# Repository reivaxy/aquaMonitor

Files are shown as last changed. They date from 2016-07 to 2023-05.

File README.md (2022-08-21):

# aquaMonitor

### Warning: I'm no longer working on this project, I'm replacing it with iotinator (https://github.com/reivaxy/iotinator) which is not focused on aquarium monitoring but provides a framework to monitor and/or control "anything" in your house (including aquariums), with a modular architecture, smaller and cheaper components.

The esp8266 evolution (which is working) will never be more than a prototype, while the earlier version (No wifi, only in and out SMS) is fully functional, two devices currently running 24/7 since spring 2015.)

AquaMonitor is a device to monitor a recifal aquarium (or reef tank) with an Arduino Mega board and send SMS alerts when vitals are bad.

Monitors light level, temperature, water level, main power failure, and sends SMS to all registered mobile phone numbers when configurable thresholds are reached.

Settings (thresholds for light and temperature, light schedule, ...) are all managed through sending SMS (or via a web application for the prototype with ESP8266)

WebApp showing a light level alert | Example of SMS communication
-------|-------
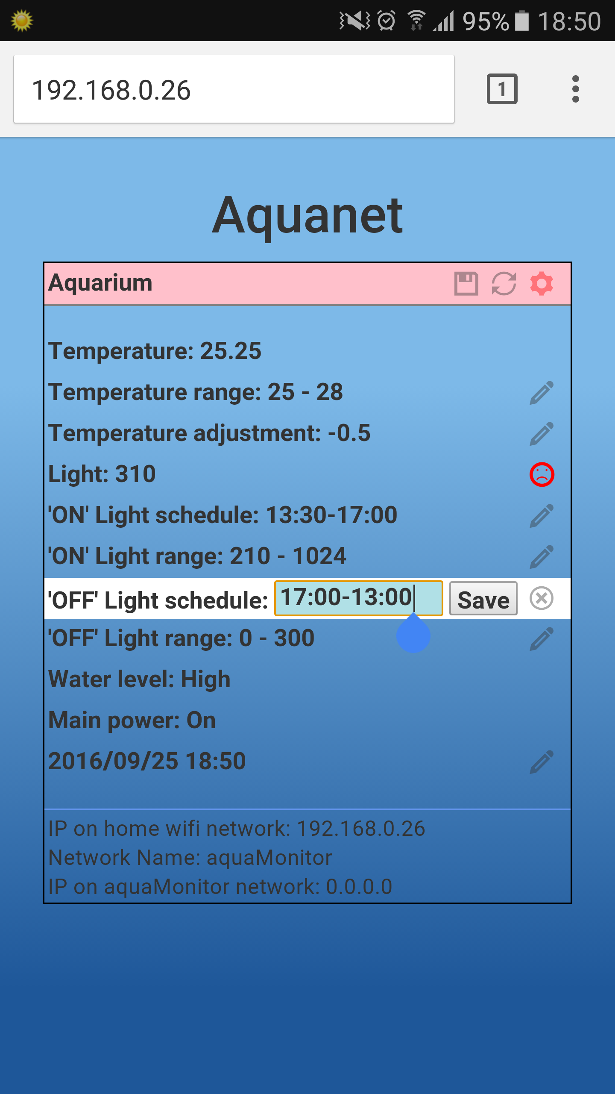
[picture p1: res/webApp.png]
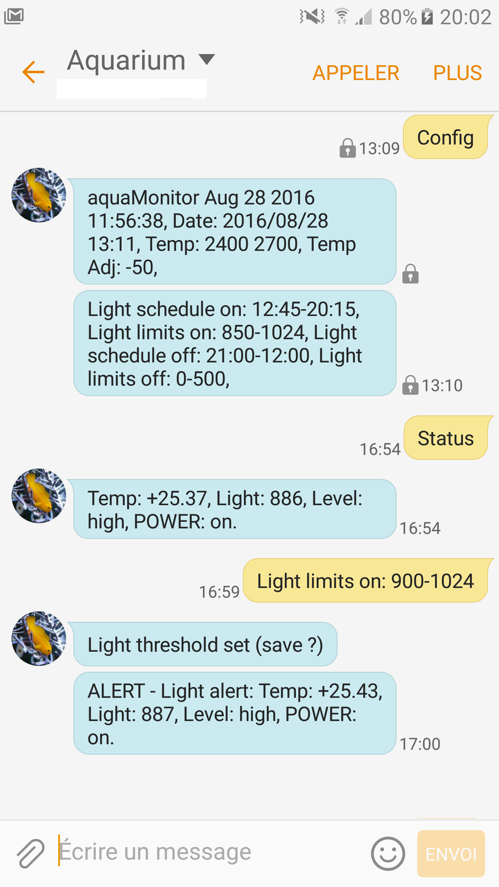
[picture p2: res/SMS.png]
 | 

Chart displaying evolution of parameters:<br/>
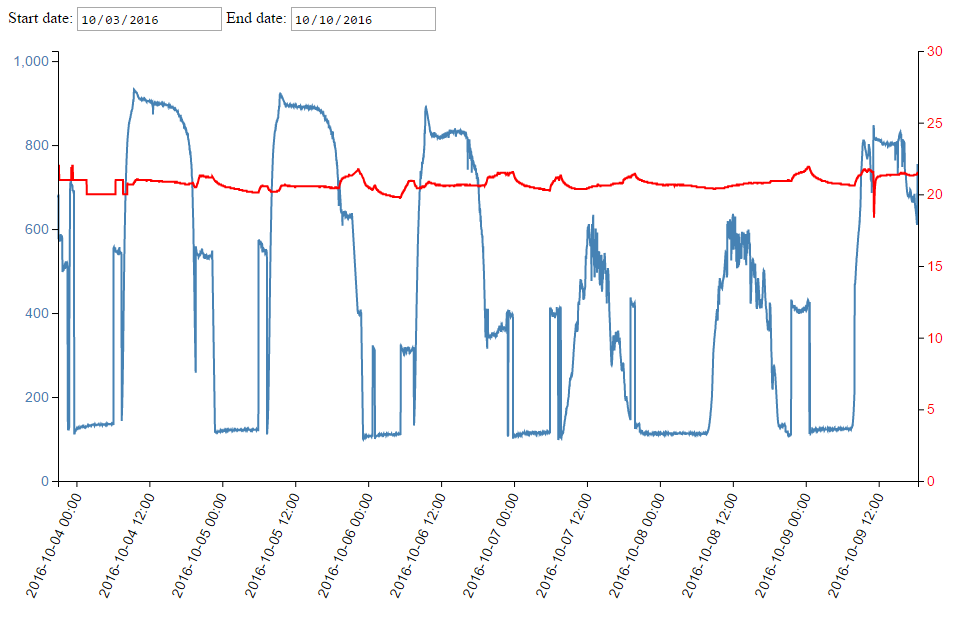
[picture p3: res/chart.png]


Device installed:<br/>
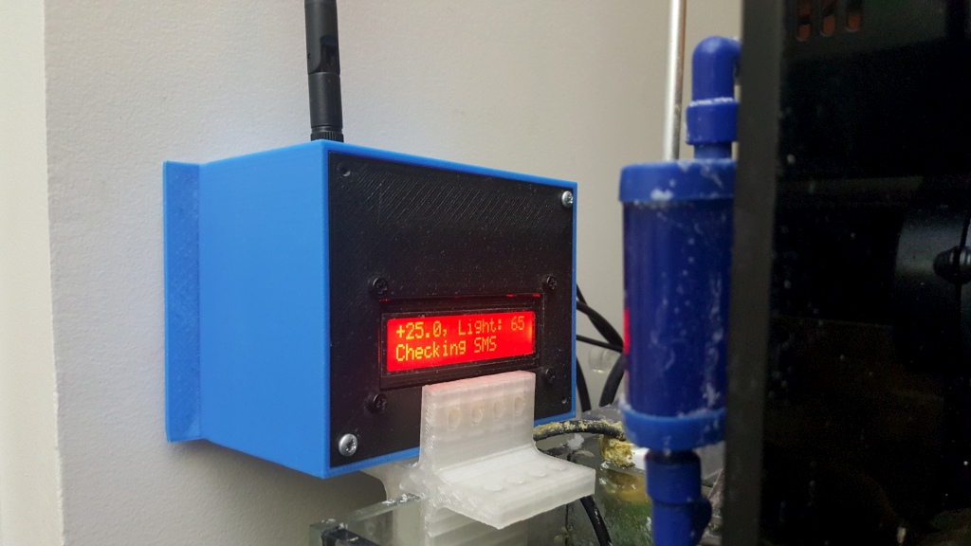
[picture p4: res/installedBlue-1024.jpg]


Although project comes with 3D files to print the <a href="https://github.com/reivaxy/aquaMonitor/blob/master/hardware/bracket/aquaMonitorDemo.stl">triple sensor bracket (light, temperature and adjustable water level sensor)<a> and <a href="https://github.com/reivaxy/aquaMonitor/blob/master/hardware/case/case.stl">case</a>, you dont *need* a 3D printer, you can instead use a case from the market and design your own fixture for the sensors.

A PCB design (for Fritzing http://fritzing.org/home/) is provided, you can either order the PCB, make it yourself, or use a prototyping board instead.

Disclaimer: This system description is provided with no warranty whatsoever. If you use it, you accept to do so at your own risks, should a bug or any event be the cause of a malfunction.
Originally supposed to run on a UNO board, this project does not take full advantage of more advanced Mega board features.

# Libraries to add:
* MAX31850 OneWire (adafruit)
* EEPROMx
* RTC (included in this repo, not sure where it comes from)
* ArduinoJson (https://github.com/bblanchon/ArduinoJson)

# Available features
* Temperature periodical measurement
* Light periodical measurement
* Water level (high/low) detection
* Main power monitoring
* LCD scrolling display of these measures
* Connects to home wifi network
* Expose a webApp to monitor and set the parameters
* Periodically sends measures to an external website to provide charts
* Sending SMS with light, temperature, main power and water level when thresholds are reached
* Can subscribe/unsubscribe a new phone number to alerts by sending an SMS.
* Adjusting the high/low light threshold and schedules by SMS
* Adjusting the temperature value by SMS
* Adjusting the time interval when light should be on.
* Save and read params (thresholds...) to EEPROM
* Battery in case main power fails.
* Most strings stored in PROGMEM to save variable memory space, easily localizable.
* Each subscribed phone numbers can set a minimum interval between 2 alerts to avoid flooding
* Periodical checking for incoming SMS, handles messages like :
  * 'admin +33xxxxxxxx' : add this phone number with admin rights
  * 'config' : send back the config
  * 'display': Reset the display when messy (prototype contact issue ?, investigating)
  * 'interval xxx' : No more than 1 sms per xxx seconds
  * 'light XXX' : set the low light threshold for alerts
  * 'save': save the configuration (light schedule and level, temp range, subs, admin, ...) to EEPROM
  * 'schedule hh:ss - hh:ss' : set the time span during which light should be above threshold
  * 'status': send SMS back with current measures
  * 'reset sub': resets all subscriptions (admin only)
  * 'sub xxx' : subscribe to a service (alert, event)
  * 'subs' : send back list of subscribed phone numbers (admin only)
  * 'temp XXX YYY': set the low (XXX) and high (YYY) thresholds for temperature
  * 'temp adj XXX': set the temperature adjustment signed value
  * 'time 2016/07/30 11:00' : set the date and time
  * 'unsub xxx' : unsubscribe to a service (alert, event)

# TODOs
* Water movement detection to warn about pumps failure (sensor remains to be found or designed...) 
* Some more configuration by SMS (level detection switch state inversion for instance, or display shift frequency ?)
* Periodical status sending (upon registration) ?
* see roadmap for bigger planned changes (Local Access Point for slave devices to connect to)

# More pictures 

Prototype (at the time it could run on a UNO board):<br/>
<br/>

<br/><br/>
Finished:<br/>
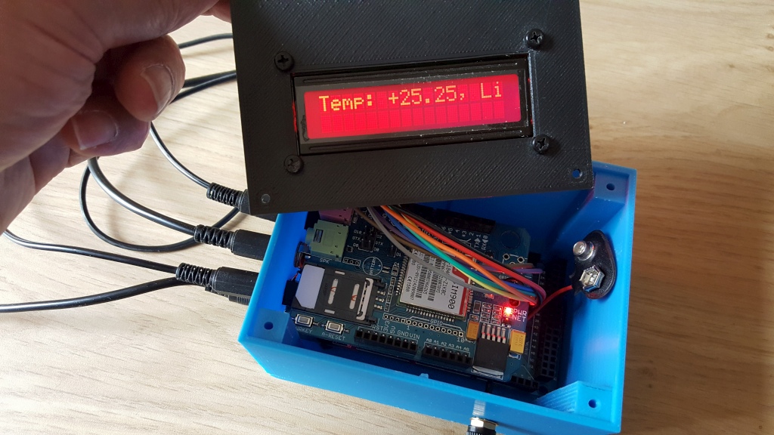
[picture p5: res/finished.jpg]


Other device installed:<br/>
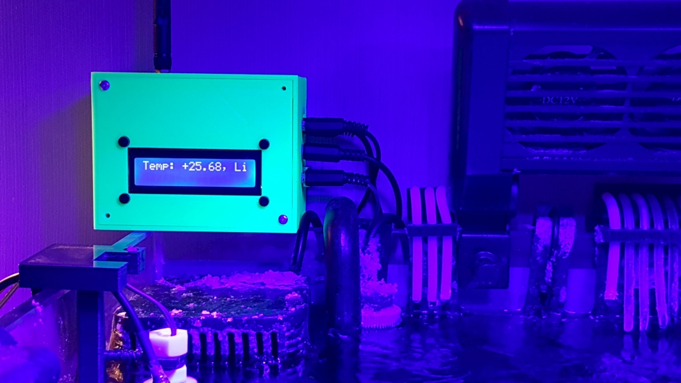
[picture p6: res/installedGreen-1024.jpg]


<br/><br/>
Sensors:<br/>


<br/><br/>

#License

<br />This work is licensed under a <a rel="license" href="http://creativecommons.org/licenses/by-nc/4.0/">Creative Commons Attribution-NonCommercial 4.0 International License</a>.

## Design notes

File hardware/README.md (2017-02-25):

# Hardware

This is the hardware stuff you'll need to build it all.

<b>Beware: schematics and PCB not yet updated with the Wifi module ESP8266. Coming soon.</b>

Here is the schematic:

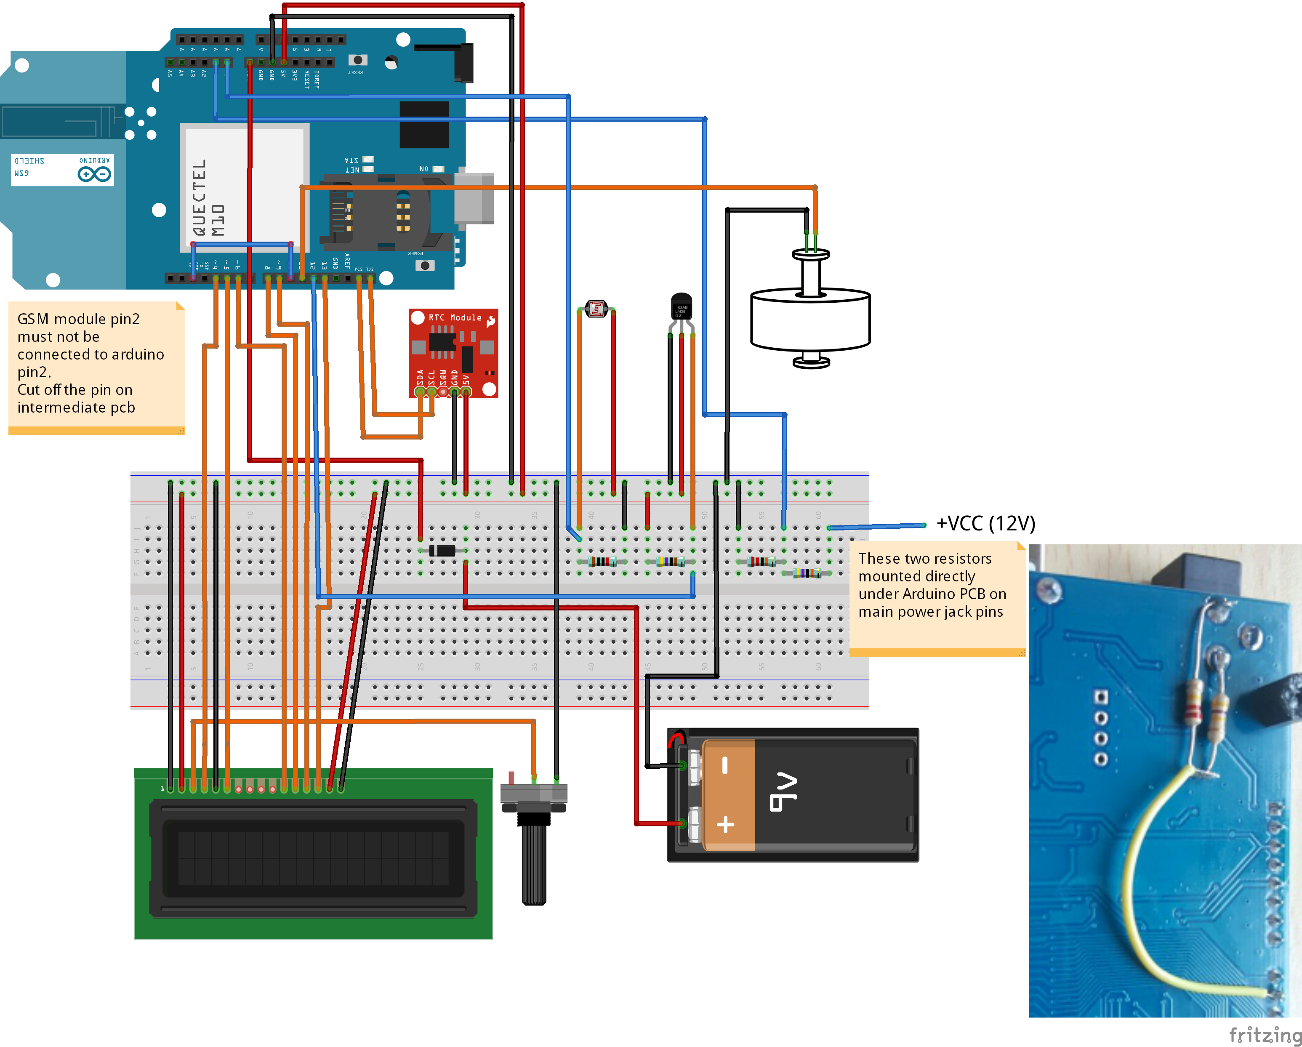
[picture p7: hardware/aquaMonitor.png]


The PCB:

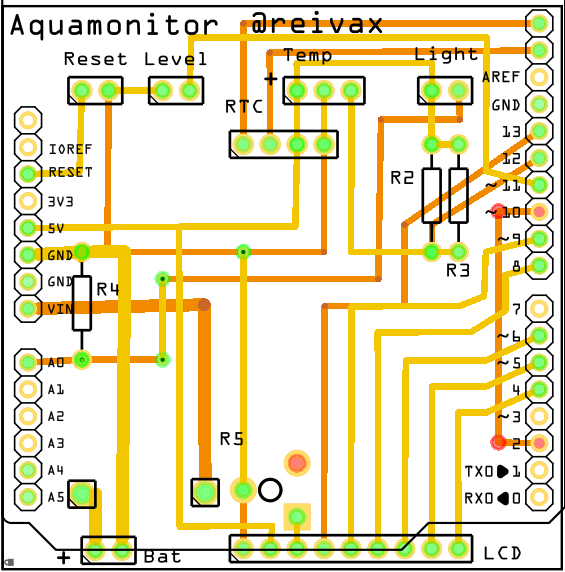
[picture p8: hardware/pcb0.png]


Here is the sensor bracket body design:



and the adjustable water level sensor bracket:



Here is the main body printed, with an unfinished prototype for the adjustable water level sensor bracket:





And, finally:







# License

<br />This work is licensed under a <a rel="license" href="http://creativecommons.org/licenses/by-nc/4.0/">Creative Commons Attribution-NonCommercial 4.0 International License</a>.

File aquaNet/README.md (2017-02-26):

# aquaNet

This is the code for the optional ESP8266 Wifi device that will allow you to:
* Access aquaMonitor through a web interface to modify the settings and run commands
* Have aquaMonitor periodically log measures to an external web site in order to build statistics
* Have several aquaMonitor modules share one GSM (hence one SIM card) to send alerts.

Use the Arduino IDE to build and upload the binary to your ESP8266 module.
The steps to set up the IDE are described here: http://randomnerdtutorials.com/how-to-install-esp8266-board-arduino-ide/

The embedded web server actually serves a minimalistic page (whose content is a string in html.h) that loads scripts **from an external web site you own**, that builds the webApp.
It makes styling the page very easy and with no need to flash the wifi module again. So most of the webApp is actually in the '<a href="https://github.com/reivaxy/aquaMonitor/tree/master/aquaNet/webSite/www/aquaNet">webSite/www/aquaNet</a>' subdirectory.

It uses jQuery, Backbone and Boostrap.

Here is what the webApp currently looks like, showing data for one module, with an alert on the light level while editing a light setting.



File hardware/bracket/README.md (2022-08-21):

The aquaMonitor.scad file contains two modules, each needs to be rendered separately and printed:

The main body, and the insert.

New version: the light sensor is enclosed in the bracket, to avoid salt and corrosion (four sensors died because of it already). This means the bracket needs to be printed with transparent ABS or PET. 

You can check the <a href="https://github.com/reivaxy/aquaMonitor/blob/master/hardware/bracket/aquaMonitorDemo.stl">aquaMonitorDemo.stl file to see a 3D rendering of the bracket</a> with its insert positionned.

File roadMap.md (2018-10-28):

Warning: this project is asleep, while I'm working on iotinator which should replace it with much better modular architecture, smaller and cheaper components, and many more features. The esp8266 version is still a prototype, while the earlier version is fully functional, two devices currently running 24/7 since spring 2015.)

#V1.0 2016/09
- Full config via SMS
- config saved in EEPROM
- monitors water level, light on level and schedule, light off level and schedule, temperature, main power
- send alerts via SMS
- logs info on serial line
- LCD display 2x20 with measures and messages
- battery backup
- extra phone numbers subscription to get alerts

#Planned evolutions

Hardware stuff:
- Investigate replacing LCD screen with Oled screen ?. Ordered for prototyping, here is the look:

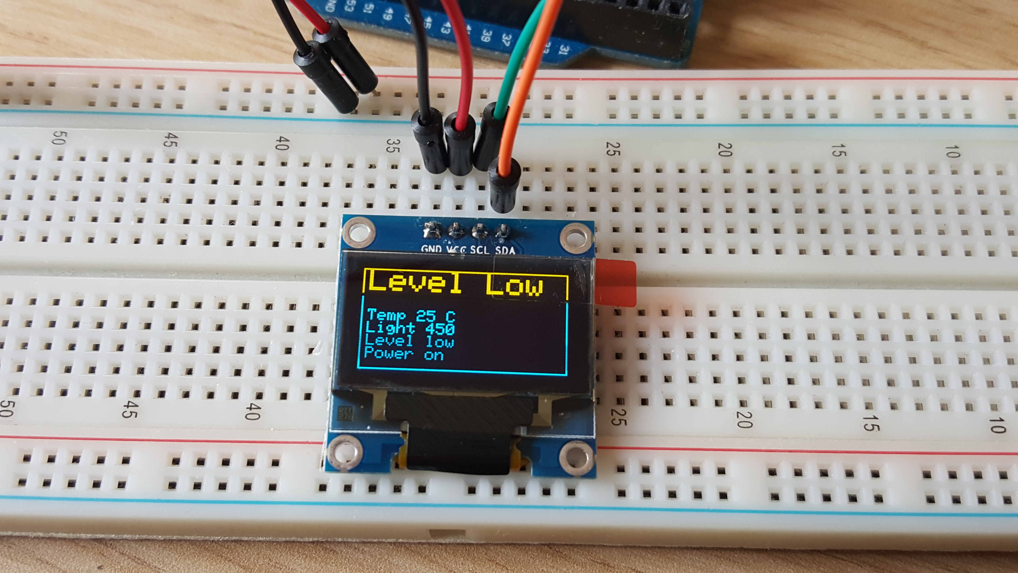
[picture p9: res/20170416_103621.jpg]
 

  Nice thing is low consumption.

- replace the 3 jack sockets with a DB15 socket ? Mechanical issue to fix on the case if wires are soldered. Need connectors :(

#V2.0 (now in master branch)
The software is mostly ready for V2 in master branch. Needs to make more settings accessible, and need schematics update (and new PCB)
- Connects to home wifi network, using ESP8266
 

- Logs all measures to external website
- expose a webApp allowing to see all data, and edit settings

The features below will be implemented in the "iotinator" project (ok sorry but it's hard to come up with a good name).
~~#V3.0
- Creates own private wifi network
- Monitors extra aquaMonitor devices connections. These ones won't have a GSM circuit, only wifi.
- Handles all connected devices to forward them configuration messages, and transmit their alerts by SMS.~~

~~#V4.0
- Any extra device will be able to create its own private wifi network to handle more devices
Would be useful for people owning more than 5 tanks. I know one.
(wifi component only accepts 4 simultaneous connections. Could multiplex, but less fun, and not as quick)~~

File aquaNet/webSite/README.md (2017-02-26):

#Statistics web server and webApp files host

This server provides an access point to record tank measures (from different tanks and users) into a database, as well as a page to display a graph from the data for a given tank:



The content of the www directory needs to be uploaded to a publicly accessible web server.

This web server hostname needs to be set into DEFAULT_WEBAPP_HOST constant in aquaMonitorSecret.h file (file that needs to be accessible when compiling the arduino and the ESP8266 firmwares, obviously not included in this repository).

The credentials to connect to your mySQL DB need to be set in the includes/myconfig.inc.php file, that must not be accessible through your server url.

The reeftanklpaqua.sql file should be used to create the DB structure (run it from command line or phpMySqlAdmin)

(Beware, there is no authentication yet between the arduino wifi module and the server, so anyone knowing the endpoints can inject data)

The www/aquaNet subdirectory contains files for the aquaNet webApp, which is a web application exposed by the wifi module.

The js and css files are loaded from the minimalist loader page served by the module to build the webApp, which allows to modify the webApp without the need for flashing the ESP8266 to improve the look, or translate messages.
This also makes using images really easier, and contributes to faster page loading, since the wifi module does not have a great bandwidth (and does not process multiple requests simultaneously).

Of course this is made possible thanks to the .htaccess directive:

Header set Access-Control-Allow-Origin "*"

The test.html page can be used to test the webApp, it will then use the getData.json test data.
It anticipates on V3 features, allowing to display data from several connected modules.

All translatable labels used in the webApp are in a css file, that will make localisation easy.

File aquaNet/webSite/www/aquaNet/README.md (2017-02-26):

#aquaNet Web application

This directory hosts the main part of the webApp exposed by the ESP8266 wifi module on the wifi local network it creates.

This external hosting makes it easy to modify the webApp with no need to flash the ESP8266, is much more convenient when using images, and provides much better performances.



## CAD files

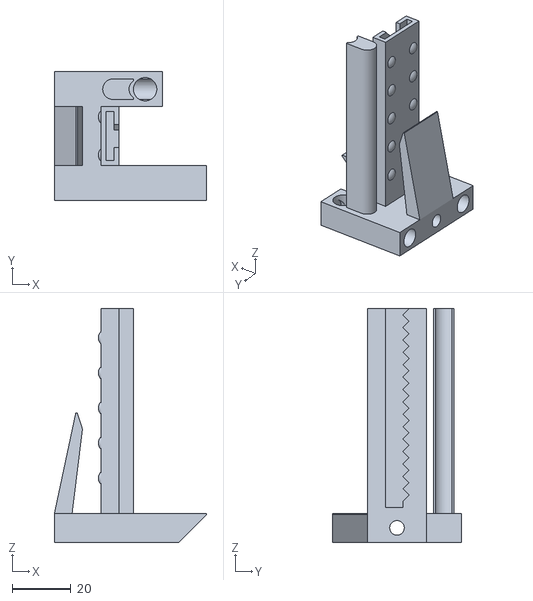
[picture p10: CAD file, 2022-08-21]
hardware/bracket/aquaMonitor6mm.stl
52.0 x 44.0 x 80.0

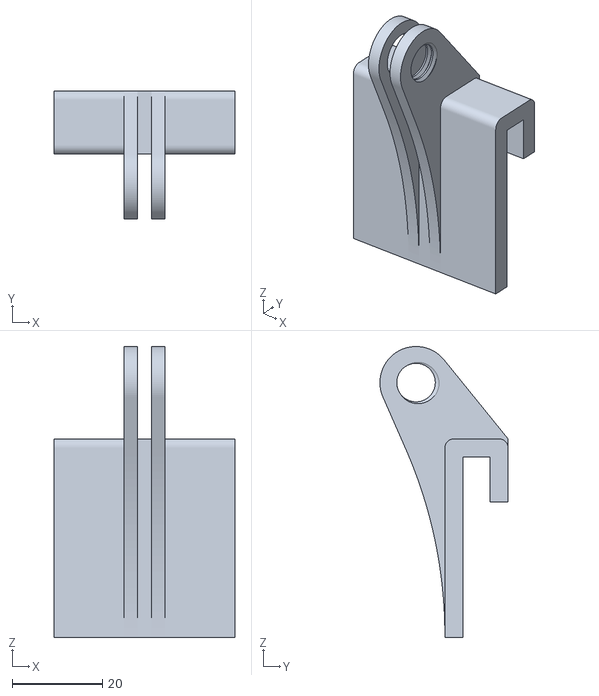
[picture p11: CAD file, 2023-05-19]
hardware/case/clamp6mm.stl
40.0 x 28.4 x 64.5

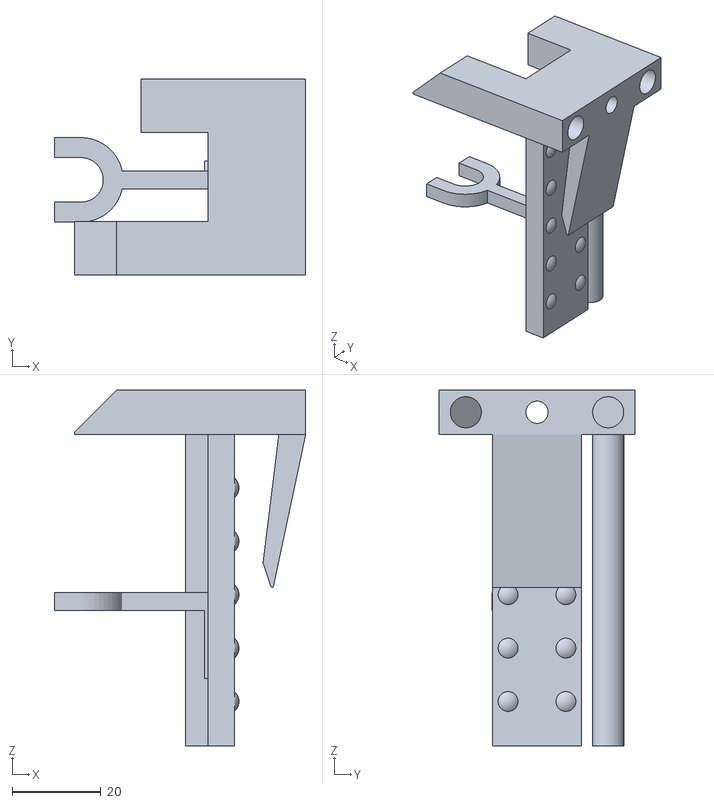
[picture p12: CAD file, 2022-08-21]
hardware/bracket/aquaMonitorDemo.stl
56.5 x 44.0 x 80.0

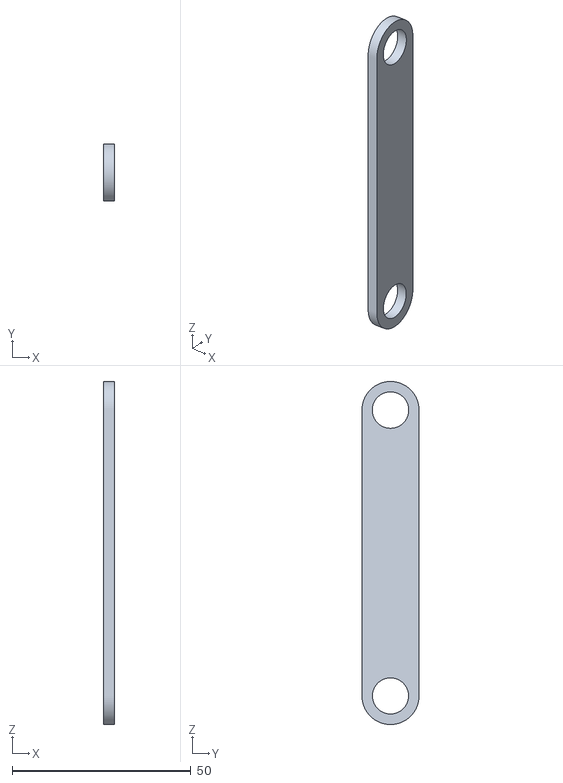
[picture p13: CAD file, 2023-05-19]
hardware/case/leg.stl
3.00 x 16.0 x 96.0

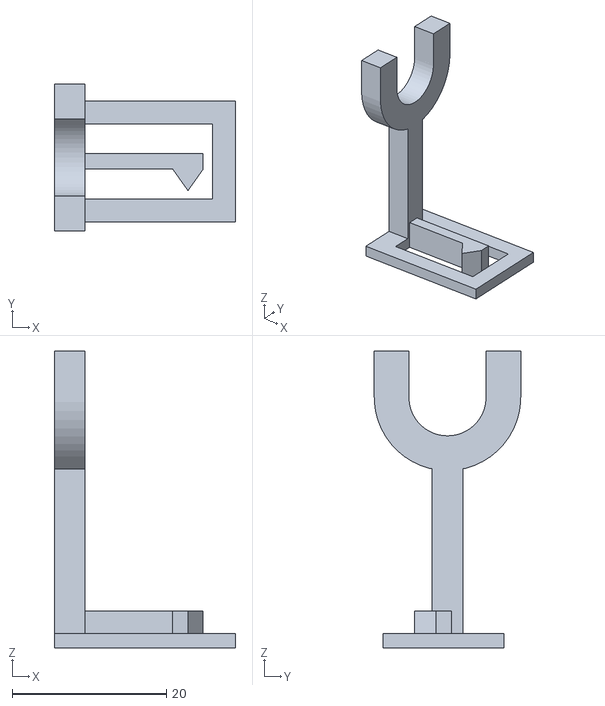
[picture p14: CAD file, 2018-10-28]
hardware/bracket/insert.stl
23.5 x 19.0 x 38.5

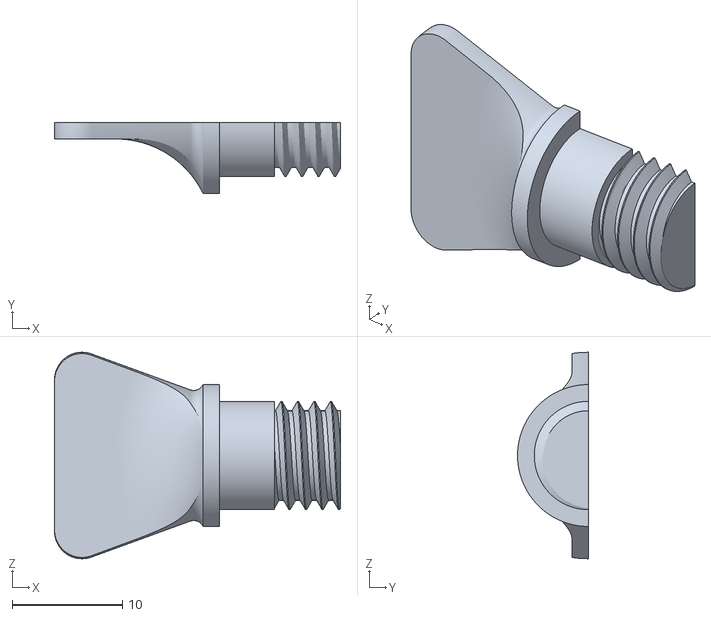
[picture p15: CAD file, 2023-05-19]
hardware/case/tightener.stl
26.0 x 6.45 x 18.8

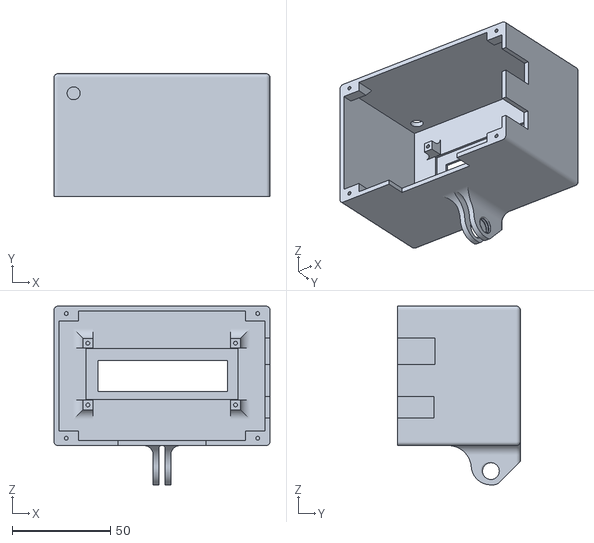
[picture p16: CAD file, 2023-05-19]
hardware/case/case.stl
110.0 x 62.5 x 91.0

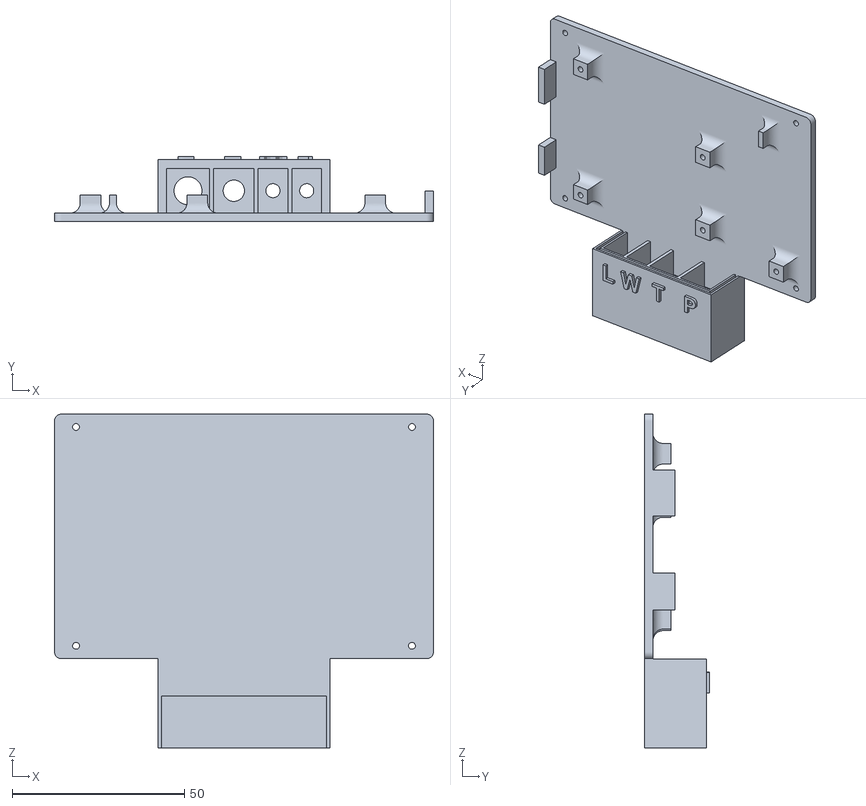
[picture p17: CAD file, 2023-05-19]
hardware/case/bottom.stl
110.0 x 19.0 x 96.9

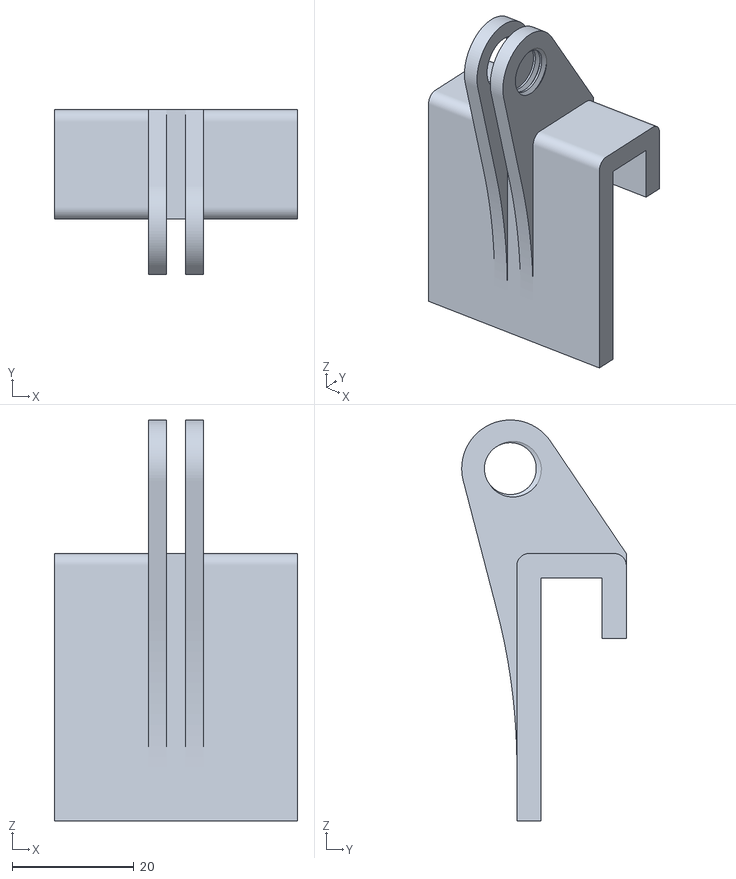
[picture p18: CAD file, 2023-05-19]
hardware/case/clamp10mm.stl
40.0 x 27.1 x 66.0

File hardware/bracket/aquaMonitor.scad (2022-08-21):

glassX = 6;
railZ = 6;
railY = 20;
railX = 70;
railWall = 2;
railSlotY = 6;

teeth = 3;

teethZ = railZ - railWall;
teethOffset = sqrt(pow(teeth, 2)/2);

pawlTeeth = teeth - 0.2;
pawlTeethOffset = sqrt(pow(pawlTeeth, 2)/2);

sphereD = 6;
topRecessX = 15;
levelWireTubeDiam = 5;
wireTubeDiam = 7;

topZ = 10;
topX = glassX + 4 + 2 * railZ + topRecessX;
topY = 44;

insertLength = 23.5;
insertBorder = 3;
insertWidth = railY - 2*railWall -0.3;
insertHeight = railZ - 2*railWall -0.1;
insertPawlWidth = 2;
 
armHeight = 24;
armWidth = insertBorder+1 ;


// Bracket body
//body();


// Insert
//insert();

//lightShield();

// Demo
demo();




// Insert positionned within bracket, for demo, not printing.
module demo() {
  rotate([0, 180, 0]) {
    body();
    translate([topX - topRecessX - railZ + railWall,  
              insertWidth + (topY - railY)/2 + railWall,
              railX - insertLength -1]) {
      rotate([180, -90, 0]) {
        insert();
      }
    }
    translate([topX - wireTubeDiam + 1, (topY - railY)/4, 0]) {
      rotate(180, [0, 1, 0]) {
        //lightShield();
      }
    }
  }
}


module lightShield() {
  difference() {
    intersection() {
      difference() {
        sphere(d = wireTubeDiam + 6 , $fn=50);
        sphere(d = wireTubeDiam + 2 , $fn=50);
      }
      translate([0, -wireTubeDiam, 0]) { 
        cube([2*wireTubeDiam, 2*wireTubeDiam, 2*wireTubeDiam ]);
      }
    }
    rotate(20, [0, 1, 0]) {
      translate([-2*wireTubeDiam, -wireTubeDiam, 0]) {   
        cube([2*wireTubeDiam, 2*wireTubeDiam, 2*wireTubeDiam ]);
      }
    }
  }
}

module insert() { 
  extDiam = 9.5;
  intDiam = 5;
  
  difference() {
    cube([insertLength, insertWidth, insertHeight]);
    translate([insertBorder, insertBorder, -0.5]) {
      cube([insertLength - 2*insertBorder,
         insertWidth - 2*insertBorder, insertHeight + 3]);  
    }
  }
  // Pawl with tooth
  pawlHeight = 2*insertHeight + 1;
  translate([0, (insertWidth - insertPawlWidth)/2, 0]) {
    pawlLength = insertLength - insertBorder - 1.2;
    cube([pawlLength, insertPawlWidth, pawlHeight]);
    translate([pawlLength - pawlTeethOffset*2, 0, 0]) {
      linear_extrude(height = pawlHeight) {
        polygon([[0, 0], [pawlTeethOffset, - pawlTeeth], [pawlTeethOffset*2, 0]]);
      }
    }
  }
  // Thicker border at Pawl attachement
  cube([armWidth, insertWidth, insertHeight]);

  // small shift 
  translate([0, 0.5, 0]) {  
    // Vertical arm
    translate([0, (insertWidth - armWidth)/2, 0]) {
      cube([armWidth, armWidth, armHeight]);
    }
    // open ring for level sensor 
    translate([0, insertWidth/2, armHeight + extDiam - 1]) {
      rotate([0, 90, 0]) {
        difference() {
          union() {
            cylinder(r=extDiam, h=armWidth, $fn=50);
            translate([3-extDiam, -extDiam, 0]) {
              cube([extDiam - 3, extDiam*2, armWidth]);
            }
  //          linear_extrude(height = armWidth) {
  //            polygon([[0, extDiam], [extDiam*3, 0], [0, -extDiam]]);
  //          }          
          }
          translate([0, 0, -0.5]) {
            cylinder(r=intDiam, h=armWidth+1, $fn=50);
          }
          translate([-intDiam*2, -intDiam, -0.5]) {
            cube([intDiam *2, intDiam*2, armWidth +1]);
          }        
          translate([-extDiam-3, -extDiam -0.5, -0.5]) {
            cube([extDiam - 3, extDiam*2 + 1, armWidth +1]);
          }        
        }
      }
    }
  }
  
}

module body() { 
  difference() {
    union() {
      cube([topX, topY, topZ]);
      cube([topX + 15, (topY - railY)/2, topZ]);
    }
    translate([topX - topRecessX, (topY - railY)/2, -0.5])
      cube([topRecessX + 1, railY, topZ + 1]);
    
    // Hole for level sensor wires
    translate([-1, topY/2, topZ/2])
      rotate(90, [0, 1, 0])
        cylinder(d=levelWireTubeDiam, h=topX + 1, $fn=50);
    
    // Horizontal hole for light sensor wires
    translate([-2, (topY - railY)/4, topZ/2]) {
      rotate(90, [0, 1, 0]) {
        difference() {
          cylinder(d=wireTubeDiam, h=topX + 17, $fn=50);
            translate([-wireTubeDiam*2, -wireTubeDiam*2, topX + 26]) {
              rotate(45, [0, 1, 0]) {
                cube([wireTubeDiam*4, wireTubeDiam*4, 10]);
            }
          }
        }
      }
    }
    // inclined cut for light sensor
    translate([topX + 5.5 , -6, 0])
      rotate(45, [0, 1, 0])
        cube([20, 4*topZ, 4*topZ]);
 
    
    
    // Horizontal hole for temperature sensor wires
    translate([-2, topY - (topY - railY)/4, topZ/2])
      rotate(90, [0, 1, 0])
        cylinder(d=wireTubeDiam, h=topX, $fn=50);
    
    // Vertical hole for temperature sensor
    translate([topX - wireTubeDiam + 1 , topY - (topY - railY)/4, topZ/2])
      cylinder(d=wireTubeDiam+1, h=topZ, $fn=50);     
  }
  translate([topX - wireTubeDiam - 10, topY - (topY - railY)/4 - wireTubeDiam/2, topZ])
    temperatureSensorGuide();
  
  translate([topX - topRecessX - railZ, railY + (topY - railY)/2, topZ])
    rotate([0, -90, 180])
      rail();
  
  
  translate([0, (topY - railY)/2, topZ])
    rotate([0, 7, 0])
      press();
}

module temperatureSensorGuide() {
  translate([0, wireTubeDiam/2, 0])
    cylinder(d = wireTubeDiam, h = railX, $fn = 50);
  difference() {
    cube([7, wireTubeDiam, railX]);
    translate([9, wireTubeDiam/2, -0.5])
      cylinder(d = wireTubeDiam, h = railX + 1, $fn = 50);
  }
}

module press() {
  difference() {
    cube([railZ, railY, railX/2]);
    rotate([0, 5, 0]) {
      translate([-railZ, -0.5, 0])
        cube([railZ, railY+1, railX]);
    }
    translate([railZ+3, -0.5, railX/3])
      rotate([0, -25, 0]) {
        cube([railZ, railY+1, railX/2]);
    }    
  }

}

module rail() {
  difference() {
    railBody();
    translate([railWall, railY - 2*railSlotY, 2*railWall-0.5]) {
      railTeeth();
    }
  }
}

module railBody() {
  difference() {
    union() {      
      cube([railX, railY, railZ]);
      for(i = [1:1:railX/(2*sphereD)]) {
        translate([i*2*sphereD, (railY - sphereD)/4, sphereD/2 - 1 ])
          sphere(d = sphereD , $fn=50);
        translate([i*2*sphereD, railY - (railY - sphereD)/4, sphereD/2 - 1 ])
          sphere(d = sphereD , $fn=50);
      }        
    }
    translate([railWall, railWall-0.3, railWall - 0.3])
      cube([railX , railY - 2*railWall+0.6, railZ - 2*railWall + 0.6]);
  }
}

module railTeeth() {
  cube([railX , railSlotY, teethZ]); 
  for(i = [1:1:railX/(teethOffset*2)]) {
    translate([teethOffset *2* i, -teethOffset, 0])
      rotate(45, [0, 0, 1]) {
        cube([teeth , teeth, teethZ]);  
    }
  }
  
}

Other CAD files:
hardware/bracket/aquaMonitor10mm.stl
hardware/case/tightener (1).stl

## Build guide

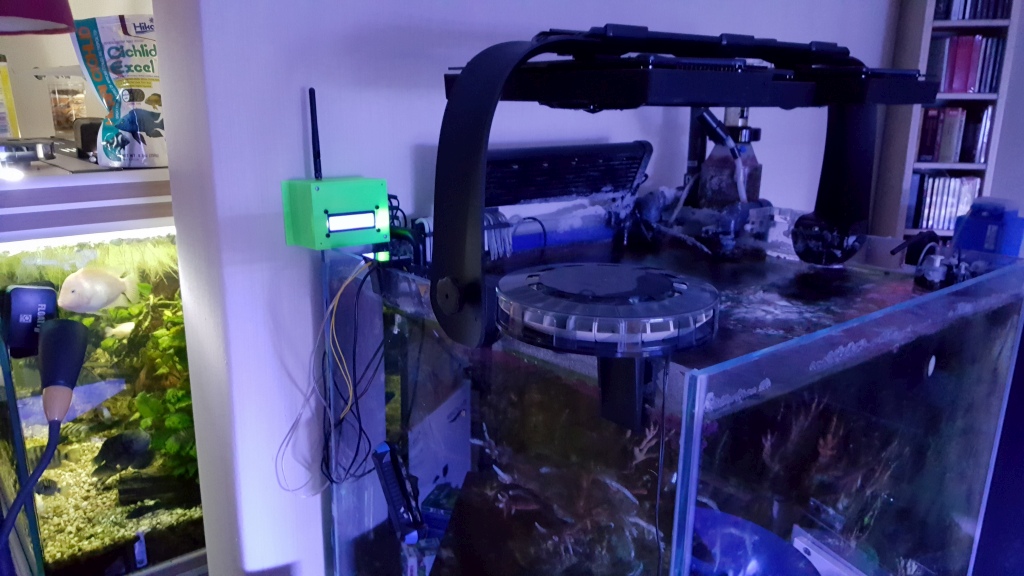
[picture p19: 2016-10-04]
res/installedGreen2-1024.jpg

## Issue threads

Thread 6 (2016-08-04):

Monitor main power source

reivaxy, 2016-08-04:
Main power source should be monitored to send an SMS as soon as it fails, since the battery may not last long enough to wait for temperature to drop or, if it happens during lights off schedule.

Use a resistor divider bridge on main power (12V) to drive an arduino input.

NullFragment, 2016-08-04:
Are you asking for what resistors to use for the voltage divider?

In that case, using a normal voltage divider rule,

- R1 = 9.1k
- R2 = 6.2k + 300 Ohm in series

Where

NullFragment, 2016-08-04:
Are you asking for what resistors to use for the voltage divider?

In that case, using a normal voltage divider rule,

- R1 = 9.1k
- R2 = 6.2k + 300 Ohm in series

Where

- +12V is attached to side 1 of R1
- Arduino Power is connected to the junction of R1 side 2, R2 side 1.
- GND is attached to side 2 of R2

reivaxy, 2016-08-04:
Hi,
Thanks, no I know how to make the divider, it's just a reminder that I need to do it :)
I think I'll use slightly higher values though, to drain even less current.
But thanks again.

reivaxy, 2016-08-29:
Updated schematics and software, all is working nicely.

Closed 2016-08-29.

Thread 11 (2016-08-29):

Probable issue if module runs for 50 days without being reset

reivaxy, 2016-08-29:
The anti-sms-flood interval for each number that receives an alert stores the value returned by millis() when sending an SMS alert.
Next time sending alerts is checked, it compares the elapsed time between this value and the current millis() value.
But millis() resets every 50 days approximately. The stored value, before the reset, will then be bigger than any millis() returned value for the next 50 days => no more alerts sent.

reivaxy, 2016-08-30:
Needs more investigation, a while ago I thought it would not be an issue (and wrote it down!)

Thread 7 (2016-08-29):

Time since last alert was sent is always 0

reivaxy, 2016-08-29:
In the "subs" reply, for each registered number, time elapsed since the last alert was sent should be available, and is currently always 0.
The data seems to be fine, since no new alert is sent before the configured interval has elapsed, but it is always 0 in the sms sent.

reivaxy, 2016-08-29:
Fixed

Closed 2016-08-29.

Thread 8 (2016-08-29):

Jack socket for temperature can short circuit the 5V arduino power => destroy the regulator

reivaxy, 2016-08-29:
And changing the regulator ain't enough, I've now 1 Mega board that runs only with USB power source, and the other delivers only 3.3V...

I may end up using VGA sockets, grouping all sensors, and with spare space for new stuff if needed...

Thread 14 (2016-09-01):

Replace DS1307 RCT with another kind.

reivaxy, 2016-09-01:
DS1307 is buggy and freezing when the button battery is in place.
http://forum.arduino.cc/index.php?topic=411697

The RTC battery isn't completely necessary, since the whole device has its own battery insuring date/time won't be lost in case of main power failure.
But still. It's annoying.

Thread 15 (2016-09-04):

No longer compiles with Arduino 1.6.11

reivaxy, 2016-09-04:
Issues with constant strings parameters
Issues with GSM library

reivaxy, 2016-09-04:
Fine with Arduino 1.6.8 and alternate GSM library
will do for now

Closed 2016-09-04.

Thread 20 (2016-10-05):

Case should be redesigned using openScad

reivaxy, 2016-10-05:
Will be handy for V3 'station' modules that do not have the GSM shield => case can be smaller

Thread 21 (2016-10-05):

Design a light shield to make sensor less sensitive to external lights

reivaxy, 2016-10-05:
Shaped as a quarter (or less) of a sphere, to glue on top of the current sensor bracket to shield the photoresistor from getting some external light

reivaxy, 2017-02-25:
Done

Closed 2017-02-25.

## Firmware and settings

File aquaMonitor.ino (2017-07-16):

#include <OneWire.h>
#include <GSM.h>
#include <EEPROMex.h>
#include <EEPROMvar.h>
#include <Wire.h>
#include "DS1307.h"
#include "aquaNet/interComMsg.h"
#include "aquaNet/common.h"
#include <ArduinoJson.h>

// 'admin' phone number defined outside of open source file haha !
// This file should contain a line in the likes of:
// #define ADMIN_NUMBER "+12345678910", which is the international number notation
#include "aquaMonitorSecret.h"

// Compilation directives to enable/disable stuff like IR support
// Beware, 'includes' for the matching libraries need to be commented / uncommented
// In the first #if using these flags
#define WITH_LCD_SUPPORT true      // About 1,6k prog, 30B RAM  TSTWIFI

// Strings to store in progmem space to free variable space
#include "./progmemStrings.h"

// Two light schedules will be handled: one during which lights must be on, one during which lights must be off
// For each, min and max level will specify the ok value for the light sensor.
// If value is not within these limits during the specified interval, alert will be sent
struct lightSchedule {
  byte startHour;           // Hour of the begining of the interval
  byte startMinute;         // Minute of the begining of the interval
  byte endHour;             // Hour of the ending of the interval
  byte endMinute;           // Minute of the ending of the interval
  int minAcceptableValue;   // Min value for light sensor considered ok for this schedule
  int maxAcceptableValue;   // Max value for light sensor considered ok for this schedule
};

// If not declaring this prototype explicitly before calling the function, arduino compiler
// will create one *before* the definition of lightSchedule and issue a crappy error message
// because the parameter will not have the right type.
boolean checkLightSchedule(int lightLevel, lightSchedule schedule);

#define PHONE_NUMBER_LENGTH 15
#define MAX_PHONE_NUMBERS 4

#define DEFAULT_MIN_ALERT_INTERVAL 1800000 // Half an hour
struct phoneConfig {
  byte permissionFlags;
  char number[PHONE_NUMBER_LENGTH + 1];
  unsigned long lastAlertSmsTime = 0UL;  // When was last time (millis()) an alert SMS sent to that number
  unsigned long minAlertInterval = DEFAULT_MIN_ALERT_INTERVAL;  // minimum interval in milliseconds between 2 alert SMS to avoid flooding
};

// Change this version to reset the EEPROM saved configuration and/or to init date and time
// when the structure changes
#define CONFIG_VERSION 11
#define CONFIG_ADDRESS 16        // Do not use adress 0, it is not reliable (read somewhere).
struct eepromConfig {
  unsigned int version;          // Version for this config structure and default values. Always keep as first structure member 
  int temperatureAdjustment;     // Signed offset to add to temperature measure to adjust it
  int temperatureHighThreshold;  // Alert will be sent if temperature above this value (centiCelsius: 2550 is 25,50Â°)
  int temperatureLowThreshold;   // Alert will be sent if temperature below this value (centiCelsius: 2400 is 24Â°)
  lightSchedule lightOn;         // Interval during which lights should be on
  lightSchedule lightOff;        // Interval during which lights should be off
  int highLevelPinValue;         // Value (HIGH or LOW) on level pin when water level is ok
  phoneConfig registeredNumbers[MAX_PHONE_NUMBERS];  // Phone numbers to send alerts to, according to their subscriptions and permissions
  int powerThreshold;            // Alert will be sent if main power input pin below this value
} config;

#define ONE_STATUS_MSG_LENGTH 20
struct displayData {
  char statusMessage[300];
  // the message is scrolling across the first display line
  // offset keeps track of the first message char to display
  unsigned char offset = 0;
  // TODO size below should somehow be LCD width, but what if LCD disabled with compilation directives ?
  char alertMessage[17]; // Message displayed permanently
  // Transient message will be displayed for short durations
  unsigned long transientStartDisplayTime=0;
  unsigned long transientDisplayDuration=2000; // 2 seconds
  unsigned long refreshPeriod = 300;
  unsigned long lastRefresh = 0;
} display;

struct measureData {
  int light = 0;
  boolean lightAlert = false;
  int powerLevel = 0;
  boolean powerAlert = false;
  int temperature; // decadegrees: 2500 for 25.00°
  boolean temperatureAlert = false;
  boolean waterLevelAlert = false;
  boolean oneAlert = false;
} measures;

// Flags for services subscriptions and permissions
#define FLAG_SERVICE_ALERT   0x01
#define FLAG_SERVICE_EVENT   0x02     // TODO : not implemented yet

#define FLAG_ADMIN           0x80

// GSM
// initialize the library instance
#define PINNUMBER "" // Pin number for the SIM CARD
GSM gsmAccess; // include a 'true' parameter for debug enabled
GSM_SMS sms;
GSMVoiceCall vcs;

// LCD
#if WITH_LCD_SUPPORT
// TODO check if still true: #include are processed no matter what (known bug) : comment or uncomment them is the only way
#include <LiquidCrystal.h>
// initialize the library with the interface pins
// GMS uses 2 and 3 (at least)
LiquidCrystal lcd(4,5,6,8,9,13);
#define LCD_WIDTH 16
#define LCD_HEIGHT 2
#endif

#define LIGHT_PIN 0         // Analog input for light sensor
#define MAIN_POWER_PIN 1    // Analog input to monitor main power
#define TEMPERATURE_PIN 12

/* DS18B20 Temperature chip i/o */
OneWire  ds(TEMPERATURE_PIN);
#define MAX_DS1820_SENSORS 1
byte addr[MAX_DS1820_SENSORS][8];

// Okay these globals are pretty bad and may still be the cause of a few bugs, but the
// small amount of variable space on UNO left me with little choice.
// May be worth redesigning all this since using Mega, now...
#define PROGMEM_MSG_MAX_SIZE 60
char progMemMsg[PROGMEM_MSG_MAX_SIZE + 1];

#define TEMPERATURE_CHECK_PERIOD 5000
unsigned long lastTemperatureCheck = millis();

#define LIGHT_CHECK_PERIOD 5000
unsigned long lastLightCheck = lastTemperatureCheck;

#define SERIAL_STATUS_PERIOD 5000
unsigned long lastSerialStatus = lastTemperatureCheck;

#define LEVEL_CHECK_PERIOD 5000
unsigned long lastLevelCheck = lastTemperatureCheck;

#define POWER_CHECK_PERIOD 5000
unsigned long lastPowerCheck = lastTemperatureCheck;

// Check for incoming sms every 30 seconds
#define SMS_CHECK_PERIOD 30000
unsigned long lastSmsCheck = lastTemperatureCheck;

// Check for incoming voice call: if not handled, will break SMS management
#define CALL_CHECK_PERIOD 6000
unsigned long lastCallCheck = lastTemperatureCheck;

// Max size of a received SMS
#define MAX_SMS_LENGTH 40
boolean gsmEnabled = true;    // TSTWIFI

#define LEVEL_PIN 11

char serialMessage[MAX_SERIAL_INPUT_MESSAGE];
char serialMessageFromESP[MAX_SERIAL_INPUT_MESSAGE];

// TODO: offer choice with DS1302 ?
DS1307 clock; // The RTC handle to get date and time

// System initialization
void setup(void) {
  serialMessage[0] = 0;
  serialMessageFromESP[0] = 0;
  Serial.begin(9600);
  Serial1.begin(9600);

  // Init pin with the level detector as input
  pinMode(LEVEL_PIN, INPUT);
  digitalWrite(LEVEL_PIN, HIGH); // Activate pullup resistor

  // During dev and debug, in case some loop goes crazy, limit the number of EEPROM writes to save it
  // TODO : this should be removed some day
  EEPROM.setMaxAllowedWrites(100);

  initLCD();

  displayTransient(getProgMemMsg(INIT_AQUAMON_MSG));
  Serial.println(getProgMemMsg(BUILD_MSG));

  // Initialise RTC
  clock.begin();

  clock.getTime();
  if(clock.year == 0) {
    setupClock();
  }

  readConfig();
  displayConfig(false, "");

  displayTransient(getProgMemMsg(TEMP_INIT_MSG));
  if (!ds.search(addr[0])) {
    displayTransient(getProgMemMsg(ADDR_ERR_MSG));
    ds.reset_search();
    delay(250);
  }
  if(gsmEnabled) {
    delay(1000);
    // Start GSM shield
    displayTransient(getProgMemMsg(INIT_GSM_MSG));
    displayTransient(getProgMemMsg(CONNECTING_GSM_MSG));
    if(gsmAccess.begin(PINNUMBER)==GSM_READY) {
      displayTransient(getProgMemMsg(CONNECTED_GSM_MSG));
      // This makes sure the modem notifies correctly incoming events
      vcs.hangCall();
    } else {
      displayTransient(getProgMemMsg(NOT_CONNECTED_GSM_MSG));
      delay(1000);
    }
  }
#if WITH_LCD_SUPPORT
  lcd.clear();
#endif
  // wait a couple seconds before starting surveillance, to avoid dummy temperature
  delay(2000);
}

// Returns pointer to the global string buffer holding a string read from PROGMEM
// This is not good but I was trying to save as much memory as possible when trying
// to make the whole thing fit on Arduino Uno.
char * getProgMemMsg(int messageId) {
  strncpy_P(progMemMsg, (char*)pgm_read_word(&messages[messageId]), PROGMEM_MSG_MAX_SIZE);
  // Just in case
  progMemMsg[PROGMEM_MSG_MAX_SIZE] = 0;
  return progMemMsg;
}

void loop(void) {
  // RTC does not have an epoch field :(
  unsigned long now = millis();
  int incomingChar = 0;
  int length;

  // Sensors are not checked at each cycle either.
  if(checkElapsedDelay(now, lastLightCheck, LIGHT_CHECK_PERIOD)) {
    checkLight();
    lastLightCheck = now;
  }
  if(checkElapsedDelay(now, lastTemperatureCheck, TEMPERATURE_CHECK_PERIOD)) {
    checkTemperature();
    lastTemperatureCheck = now;
  }
  if(checkElapsedDelay(now, lastLevelCheck, LEVEL_CHECK_PERIOD)) {
    checkWaterLevel();
    lastLevelCheck = now;
  }
  if(checkElapsedDelay(now, lastPowerCheck, POWER_CHECK_PERIOD)) {
    checkPower();
    lastPowerCheck = now;
  }
  measures.oneAlert = measures.lightAlert || measures.powerAlert || measures.temperatureAlert || measures.waterLevelAlert;

  // Display is not refreshed at each cycle but only every refreshPeriod
  if(checkElapsedDelay(now, display.lastRefresh, display.refreshPeriod)) {
    refreshDisplay();
  }

  if(measures.oneAlert) {
    sendAlert();
  }

  if(checkElapsedDelay(now, lastSmsCheck, SMS_CHECK_PERIOD)) {
    checkSMS();
    lastSmsCheck = millis(); // checkSMS is a bit slow.
  }
  if(checkElapsedDelay(now, lastCallCheck, CALL_CHECK_PERIOD)) {
    checkCall();
    lastCallCheck = now;
  }

  // Check USB serial for incoming messages
  if(readFromSerial(&Serial, serialMessage, 500)) {
    processMessageFromSerial(serialMessage);
    serialMessage[0] = 0;
  }

  // Check serial1 for incoming messages from wifi module
  if(readFromSerial(&Serial1, serialMessageFromESP, 500)) {
    processMessageFromESP(serialMessageFromESP);
    serialMessageFromESP[0] = 0;
  }

}

// Process a message sent by the ESP module
// Messages starting with '@' are arduino commands, need to be processed like SMS received
// Messages starting with '#' are ESP requests
// Other messages just need to be forwarded to usb serial (debug and log stuff)
void processMessageFromESP(char *message) {
//Serial.println("got message");
//Serial.println(message);
  // Message not starting with '#' just needs to be forwarded to USB serial
  char *colonPosition;
  char *content;
  char *firstChar = message;
  char answer[2000];
  if(*firstChar == '@') {
    // The message sent by ESP is actually a command for the arduino like the one it gets from
    // the usb serial or sms
    firstChar++; // check after first # char
    Serial.println(firstChar);
    processMessageFromSerial(firstChar);
  } else if(*firstChar == '#') {
    // The message sent by ESP is a specific ESP request
    firstChar++; // check after first # char
    colonPosition = strchr(firstChar, ':');
    if(colonPosition != NULL) {
      content = colonPosition + 1;
    }
    if(strncmp(firstChar, REQUEST_IF_GSM, strlen(REQUEST_IF_GSM)) == 0) {
      // esp wants to know if module is equipped with GSM
      sprintf(answer, "%s:%d", REQUEST_IF_GSM, gsmEnabled);
      Serial1.println(answer);
    } else if(strncmp(firstChar, REQUEST_MEASURES, strlen(REQUEST_MEASURES)) == 0) {
      char date[40]; // No need for 40, unless there is no rtc connected :)
      char lightOn[15];
      char lightOff[15]; // No need for 40, unless there is no rtc connected :)
      Serial.println("ESP wants measures");
      // esp wants to know measures to log them
      // We'll pass a json object using ArduinoJson library by Benoît Blanchon
      // size : https://rawgit.com/bblanchon/ArduinoJson/master/scripts/buffer-size-calculator.html
      StaticJsonBuffer<400> jsonBuffer;
      JsonObject& root = jsonBuffer.createObject();
      root["temp"] = measures.temperature;
      root["tempAlert"] = measures.temperatureAlert;
      root["minTemp"] = config.temperatureLowThreshold;
      root["maxTemp"] = config.temperatureHighThreshold;
      root["tempAdj"] = config.temperatureAdjustment;
      root["light"] = measures.light;
      root["lightAlert"] = measures.lightAlert;
      root["minOnLight"] = config.lightOn.minAcceptableValue;
      root["maxOnLight"] = config.lightOn.maxAcceptableValue;
      root["minOffLight"] = config.lightOff.minAcceptableValue;
      root["maxOffLight"] = config.lightOff.maxAcceptableValue;
      sprintf(lightOn, "%02d:%02d-%02d:%02d", config.lightOn.startHour, config.lightOn.startMinute, config.lightOn.endHour, config.lightOn.endMinute);
      root["lightOn"] = lightOn;
      sprintf(lightOff, "%02d:%02d-%02d:%02d", config.lightOff.startHour, config.lightOff.startMinute, config.lightOff.endHour, config.lightOff.endMinute);
      root["lightOff"] = lightOff;
      root["waterLevelAlert"] = measures.waterLevelAlert;
      root["powerAlert"] = measures.powerAlert;
      root["oneAlert"] = measures.oneAlert;
      getCurrentDate(date);
      root["date"] = date;
      sprintf(answer, "%s:", REQUEST_MEASURES);
      firstChar = answer;
      firstChar += strlen(answer);
      root.printTo(firstChar, sizeof(answer) - strlen(answer));      // ok, not pretty...
      //Serial1.println(answer);
      //Serial.println(answer);
      //writeToSerial(&Serial, answer, 500);
      writeToSerial(&Serial1, answer, 500);
    }

  } else {
    // The message sent by ESP should just be sent to USB serial
    //Serial.println(message);
    writeToSerial(&Serial, message, 500);
  }
}

// Process a message received by USB serial
void processMessageFromSerial(char *message) {
  if(*message == '#') {
    // Simulates a message received from ESP: process it as such
    processMessageFromESP(message);
  } else {
    processMessage(message, "");
  }
}

// return true if current time is after given time + delay
boolean checkElapsedDelay(unsigned long now, unsigned long lastTime, unsigned long delay) {
  unsigned long elapsed = now - lastTime;
  boolean result = false;
  // millis() overflows unsigned long after about 50 days => 0  but since unsigned,
  // no problem !
  if(elapsed >= delay){
    result = true;
  }
  if(lastTime == 0) {
    result = true;
  }
  return result; 
}

// Check water level on digital input. Returns false if low
void checkWaterLevel() {
  measures.waterLevelAlert = !(config.highLevelPinValue == digitalRead(LEVEL_PIN));
}

// return true if temperature is within low and high thresholds
void checkTemperature() {
  int highByte, lowByte, tReading, signBit, tc_100;
  byte sensor = 0;

  byte i;
  byte present = 0;
  byte data[12];

  if ( OneWire::crc8( addr[sensor], 7) != addr[sensor][7]) {
    displayTransient(getProgMemMsg(CRC_NOT_VALID_MSG));
  } else if ( addr[sensor][0] != 0x28) {
    displayTransient(getProgMemMsg(FAMILY_MSG));
  } else {
    ds.reset();
    ds.select(addr[sensor]);
    ds.write(0x44,1);         // start conversion, with parasite power on at the end

    //delay(1000);     // maybe 750ms is enough, maybe not
    // we might do a ds.depower() here, but the reset will take care of it.
    present = ds.reset();
    ds.select(addr[sensor]);
    ds.write(0xBE);         // Read Scratchpad

    for ( i = 0; i < 9; i++) {
      // we need 9 bytes
      data[i] = ds.read();
    }

    lowByte = data[0];
    highByte = data[1];
    tReading = (highByte << 8) + lowByte;
    signBit = tReading & 0x8000;  // test most sig bit
    if (signBit) // negative
    {
      tReading = (tReading ^ 0xffff) + 1; // 2's comp
    }
    tc_100 = (6 * tReading) + tReading / 4;    // multiply by (100 * 0.0625) or 6.25
    // user defined signed value to adjust temperature measure
    tc_100 += config.temperatureAdjustment;
    measures.temperature = tc_100;
    if((tc_100 < config.temperatureLowThreshold) || (tc_100 > config.temperatureHighThreshold)) {
      measures.temperatureAlert = true;
    } else {
      measures.temperatureAlert = false;
    }
  }
}

// Return true if main power is ok
boolean checkPower() {
  measures.powerLevel = analogRead(MAIN_POWER_PIN);
  // If power level less than threshold => not ok
  if(measures.powerLevel < config.powerThreshold) {
    measures.powerAlert = true;
  } else {
    measures.powerAlert = false;
  }
}

// Check if light level is within acceptable limits depending on current hour
boolean checkLightSchedule(int lightLevel, lightSchedule schedule) {
  boolean result = true;
  unsigned int startMin;
  unsigned int endMin;
  unsigned int nowMin;
  unsigned int midnight = 23*60+59;

  clock.getTime();
  startMin = schedule.startHour * 60 + schedule.startMinute;
  endMin = schedule.endHour * 60 + schedule.endMinute;
  nowMin = clock.hour * 60 + clock.minute;
  // if interval starts before midnight and ends after midnight (generally 'lights off' interval)
  // then adjustements are needed
  if(startMin > endMin) {
    if(nowMin <= startMin) {
      startMin = 0;
    } else {
      endMin = midnight;
    }
  }
  // Is current time within schedule start and end ?
  if((nowMin >= startMin) && (nowMin <= endMin)) {
    if(lightLevel < schedule.minAcceptableValue || lightLevel > schedule.maxAcceptableValue) {
      result = false;
    }
  }
  return(result);
}

// Return true if light level is within boundaries depending on current time
void checkLight() {
  measures.light = analogRead(LIGHT_PIN);
  measures.lightAlert = !checkLightSchedule(measures.light, config.lightOn) || !checkLightSchedule(measures.light, config.lightOff);
}

// Check for incoming voice call, in order to not break SMS
void checkCall() {
  switch (vcs.getvoiceCallStatus()) {
    case RECEIVINGCALL:
      Serial.println("RECEIVING CALL");
      vcs.answerCall();         
      delay(1000);
      vcs.hangCall();
      break;
  }
}

// Check for incoming SMS, and processes it if any
void checkSMS() {
  char from[PHONE_NUMBER_LENGTH + 1];
  char msgIn[MAX_SMS_LENGTH + 1];
  char c,i;
  int cptr = 0;
  if(!gsmEnabled) {
    Serial.println("NO GSM");
    return;
  }
  displayTransient(getProgMemMsg(CHECK_SMS_MSG));
  // TODO : loop to process all incoming SMS
  while (sms.available())
  {
    Serial.println(getProgMemMsg(FROM_NUMBER_MSG));
    cptr = 0;
    // Get remote number
    sms.remoteNumber(from, 20);
    Serial.println(from);

    // Any messages starting with # should be discarded
    if (sms.peek() == '#') {
      Serial.println(getProgMemMsg(DISCARD_SMS_MSG));
      sms.flush();
    } else {
      // Read message bytes
      while (c = sms.read()) {
        // If uppercase, convert to lowercase
        if ((c > 64) && (c < 91)) {
          c = c + 32;
        }
        // To be able to delete a SMS, all characters must be read
        // But only keep the max handled count
        if (cptr < MAX_SMS_LENGTH) {
          msgIn[cptr++] = c;
        }
      }
      msgIn[cptr] = 0;
      // Delete message from modem memory
      sms.flush();
      processMessage(msgIn, from);
    }
  }
}
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

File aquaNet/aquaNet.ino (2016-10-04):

#include <EEPROM.h>
#include <ESP8266WiFi.h>
#include <WiFiClient.h>
#include <ESP8266HTTPClient.h>
#include <ESP8266WebServer.h>
#include <ESP8266mDNS.h>
#include <ArduinoJson.h>
// The aquaMonitorSecret.h should be stored in a same-name sub directory of
// your libraries directory. It's obviously not in the git repository :)
// It should define these:
// #define DEFAULT_WIFI_SSID "your-home-ssid"
// #define DEFAULT_WIFI_PWD "your-home-network-password"
// #define DEFAULT_STAT_HOST "http://www.your-stat-host.com"
// #define DEFAULT_STAT_PATH "/aquaStat.php"
#include "aquaMonitorSecret.h"

// technical messages between esp and arduino
#include "interComMsg.h"
#include "common.h"
#include "html.h"

// localizable messages intended to be displayed/sent to usb serial
#include "aquaNetMessages.h"

// Structure to hold all wifi-related configuration
#define CONFIG_VERSION 'I'
#define DEFAULT_AP_SSID "aquaMonitor"    // AP ssid by default, known by all devices, can be changed
#define DEFAULT_AP_PWD  "aquaPassword"   // 8 CHAR OR MORE !! AP pwd by default so that other devices can connect
#define DEFAULT_STAT_INTERVAL  120000    // interval to send stats
#define DEFAULT_GET_MEASURES_INTERVAL  30000  // interval to send measures request to arduino
struct eepromConfig {
  unsigned char version; // Always keep it as first member when modifying this structure
  char webAppHost[50];   // hostname to host webApp files
  char statisticsHost[50]; // hostname to send statistics to; e.g. http://www.myStats.com
  char statisticsPath[50]; // path on the host to send statistics to; e.g. cgi-bin/recordStats
  char logPath[50]; // path on the host to send logs (incoming sms, voice call numbers... ?)
  unsigned long statisticsInterval = 0; // number of milliseconds between two statistic sending
  unsigned long getMeasuresInterval = 0; // number of milliseconds between two request arduino for measures
  char homeSsid[20];       // ssid to connect to (home network)
  char homePwd[65];        // Password for wifi connection
  char APSsid[20];         // ssid to create as AP for the other modules
  char APPwd[65];          // Password for the AP.
  char deviceName[20];     // Name of this device, to identify it within a network
} config;

ESP8266WebServer server(80);
MDNSResponder mdns;
int clientConnected = 0;
boolean homeWifiConnected = false;

char serialMessage[MAX_SERIAL_INPUT_MESSAGE];
unsigned long lastStatSent = 0;
unsigned long lastGetMeasures = 0;

char aquaStatus[1000]; // Json string containing data from arduino

// return true if current time is after given time + delay
boolean checkElapsedDelay(unsigned long now, unsigned long lastTime, unsigned long delay) {
  unsigned long elapsed = now - lastTime;
  boolean result = false;
  // millis() overflows unsigned long after about 50 days => 0  but since unsigned,
  // no problem !
  if(elapsed >= delay){
    result = true;
  }
  if(lastTime == 0) {
    result = true;
  }
  return result;
}

// Init config structure from EEPROM
// If not in EEPROM or version has changed from what is stored in EEPROM,
// reset config to default values, and save it to EEPROM for next time
void readConfig() {
  unsigned char i;

  unsigned int configSize = sizeof(config);
  unsigned int cptr = 0;
  byte *configPtr = (byte *)&config;
  for(cptr = 0; cptr < configSize; cptr++) {
    *(configPtr ++) = EEPROM.read(cptr);
  }

  if(config.version != CONFIG_VERSION) {
    Serial.println(WIFI_CONFIG_INIT);
    config.version = CONFIG_VERSION;
    strcpy(config.webAppHost, DEFAULT_WEBAPP_HOST);
    strcpy(config.statisticsHost, DEFAULT_STAT_HOST);
    strcpy(config.statisticsPath, DEFAULT_STAT_PATH);
    strcpy(config.logPath, DEFAULT_LOG_PATH);
    strcpy(config.homeSsid, DEFAULT_WIFI_SSID);
    strcpy(config.homePwd, DEFAULT_WIFI_PWD);
    strcpy(config.APSsid, DEFAULT_AP_SSID);
    strcpy(config.APPwd, DEFAULT_AP_PWD);
    strcpy(config.deviceName, "Aquarium");
    config.statisticsInterval = DEFAULT_STAT_INTERVAL; // number of milliseconds between two statistic sending
    config.getMeasuresInterval = DEFAULT_GET_MEASURES_INTERVAL; // number of milliseconds between two arduino msg checks

    // Save the configuration to EEPROM
    Serial.println(WIFI_CONFIG_SAVING);
    configPtr = (byte *)&config;
    for(cptr = 0; cptr < configSize; cptr++) {
      EEPROM.write(cptr, *(configPtr++));
    }
    EEPROM.commit();

    Serial.println(WIFI_CONFIG_SAVED);
  }
}

void setup(void){
  int timeout = 40;
  char ip[20];
  char message[100];

  unsigned int configSize = sizeof(config);
  serialMessage[0] = 0;

  strcpy(aquaStatus, "[]");  // No data yet
  EEPROM.begin(configSize);  // Config is read from and stored to EEPROM
  Serial.begin(9600);
  WiFi.mode(WIFI_STA);  // ap could be active from previous time

  delay(5000); // delay to connect monitor
  Serial.println("Init aquaNet");
  readConfig();

  // Connect to home network if any
  if(config.homeSsid[0] != 0) {
    WiFi.begin(config.homeSsid, config.homePwd);
    Serial.println(CONNECTING_HOME_NETWORK);

    // Wait for connection, with timeout
    while ((WiFi.status() != WL_CONNECTED) && timeout --) {
      delay(200);
    }
    if(timeout != 0) {
      homeWifiConnected = true;
      sprintf(message, CONNECTED_HOME_NETWORK, config.homeSsid);
      Serial.println(message);
    } else {
      Serial.println(CONNECTION_TIMED_OUT);
    }

    Serial.print(ACCESS_IP);
    Serial.println(WiFi.localIP());

    if (mdns.begin("esp8266", WiFi.localIP())) {
      Serial.println("MDNS responder started");
    }
  }

  server.on("/", [](){
    printHTMLPage();
  });

  server.on("/msgArduino", [](){
    // Should be only one param : the command to send to arduino
    char command[200];
    server.arg(0).toCharArray(command, 200);
    sendArduinoCommand(command);
    server.send(200, "text/plain", "");
    // To reflect updates asap
    sendArduino(REQUEST_MEASURES);
    lastStatSent = millis();  // Don't wait for response to not request again next loop
  });

  server.on("/msgESP", [](){
    // We assume there is only one param
    char command[200];
    server.arg(0).toCharArray(command, 200);
    processMessage(command);
    server.send(200, "text/plain", "");
  });

  server.on("/getData.json", [](){
    server.send(200, "text/plain", aquaStatus);
  });

  // Ask Arduino if it is equipped with GSM
  sendArduino(REQUEST_IF_GSM);

  server.begin();
  Serial.println("HTTP server started");
  //WiFi.printDiag(Serial);
}

void printHTMLPage() {
  server.send(200, "text/html", html);
  delay(1000);
}
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

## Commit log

2015-03-21 More investigation with lcd display, temperature and light sensors and GSM shield. Messages will be sent when thresholds are reached.
2015-03-22 Can now display both temperature and light thresholds
2015-03-22 Variable memory improvements, halved ! But it's pretty clear the whole thing is not going to fit on a UNO board... MEGA on its way from China...
2015-03-24 Some more IR handling. Display broken for now
    [aquaMonitor.ino]
2015-03-24 Temporarily not using F(), since it breaks all messages Added a temperature adjustment variable
2015-03-25 Fixed IR pin number incompatible with GSM Added incoming SMS checking, and status sending on 'status' sms received modified check procedures to return a boolean
    [aquaMonitor.ino]
2015-03-30 Now using PROGMEM for all text messages to save variable space Compile but may not work
    [aquaMonitor.ino]
2015-03-30 Lot of fixes. Very little memory still available. Can now save config, reset it, log it. Remaining issues with sub/unsub flag values and confirmation messages
    [aquaMonitor.ino]
2015-03-31 * Not tested * Trying to solve some buffer overflow errors
    [aquaMonitor.ino]
2015-04-01 Fixed flag handling for services sub/unsub. Remaining issue : sub/unsub messages sent by sms are truncated
    [aquaMonitor.ino]
2015-04-01 Fixed default phone number international format Fixed sub unsub messages
    [aquaMonitor.ino]
2015-04-03 Added more SMS processing to set light and temperature thresholds (since IR support was removed), config reading and saving
2015-04-05 Some fixes Non admins get an "Access denied" sms back Can now set the temp adj. parameters
    [aquaMonitor.ino]
2015-04-06 Fritzing board file and component list
    [aquaMonitor.fzz]
2015-04-07 Bug #2 Still seing broken messages in Serial, ok in SMS, to investigate.
    [aquaMonitor.ino]
2015-04-07 Limiting to 2 registered phone numbers because of memory issues. A few strings could be migrated to PROGMEM ...
    [aquaMonitor.ino]
2015-04-08 Adding a water level switch (high / low) A display manager is now reallly necessary... Coming soon
2015-04-09 Fixed level indicator display on LCD
    [aquaMonitor.ino]
2015-04-11 Added Floating switch to design for water level low alerts Added Floating switch component file for Fritzing
    [aquaMonitor.fzz]
2015-04-25 3D design for the water level, temperature and light sensors bracket
    Partial design for the adjustable mobile piece for the level sensor, it may
    need dual extrustion with PVA to hold the structure while printing it
    [aquaMonitor.FCStd, aquaMonitor.obj, aquaMonitorInsert.FCStd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]
2015-04-28 redesigned to be printed with support material
    [aquaMonitorInsert.FCStd, aquaMonitorInsert.obj]
2015-05-01 Added hole for level sensor wires Redesigned temperature sensor wire guide to better fit shape of sensor and rilsan attachement
    [aquaMonitor.FCStd]
2015-05-03 First prototype for the case. Issues: Usb and power socket holes misaligned Case too narrow because GSM shield it not aligned with main board Corners probably too narrow
    [aquaMonitor.obj, aquaMonitorCase.FCStd, aquaMonitorCase.obj]
2015-05-03 Added pullup activation on water lever input 'Normal' water level sensor value now in config (will be customizable later) Moved eeprom config start address, 0 is reputedly unreliable
2015-05-31 Added a sms command to reset the LCD display when it goes haywire
    [aquaMonitorCaseOLD.FCStd]
2015-05-31 Removed case 3D printing files. This prototype has a few design mistakes that make assembling too hard
    [aquaMonitorCase.FCStd, aquaMonitorCase.obj, aquaMonitorCaseOLD.FCStd]
2015-05-31 New case prototype.
    [aquaMonitorCase.FCStd, aquaMonitorCase.obj, aquaMonitorCaseCover.FCStd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]
2015-05-31 Fixed LCD fixation holes spacing Larger LCD fixation holes for more tolerance
    [aquaMonitorCaseCover.FCStd, aquaMonitorCaseCover.obj]
2015-06-16 Added prototype and case pictures
2015-06-16 Fixed antenna support hole diameter
    [aquaMonitorCase.FCStd, aquaMonitorCase.obj]
2016-06-20 Removed IR support Changed LCD wiring for better pcb Added pcb
    [aquaMonitor.fzz, pcb0.fzz]
2016-07-02 Wiring modified for better PCB Added PCB Added RTC init function, called when saved configuration version has changed
2016-07-02 Fixed prototype to match PCB
    [aquaMonitor.fzz]
2016-07-02 Updated pictures, added pcb and finished device.
2016-07-02 Added battery in case of main power failure. Diode probably not necessary.
    [aquaMonitor.fzz]
2016-07-02 Update README.md
    Removed IR mention, added battery
2016-07-03 Can add an admin If alert at init, sends SMS immediately First alert does not prevent other checks
    [aquaMonitor.ino]
2016-07-06 picture with finished device
2016-07-14 Begining of new bracket design with openScad: - to ease resizing and adapt to different tank glass thickness - to add anti capillarity effect leading to water overflowing tank. Old design moved to "o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
    [aquaMonitor.FCStd, aquaMonitor.obj, aquaMonitor.scad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]
2016-07-14 Progress on bracket redesign.
    [aquaMonitor.FCStd, aquaMonitor.obj, aquaMonitor.scad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]
2016-07-14 Bracket redesign complete (except for the insert), not printed yet.
    [aquaMonitor.scad]
2016-07-31 New SMS to set date and time Nice message if SIM PIN not correct Removed useless gsm init loop
    [aquaMonitor.ino]
2016-07-31 Added bracket adjustable insert with pawl Added STL files for 6mm and 10mm tank glass thickness Added demo STL with insert inside bracket
    [aquaMonitor.scad]
2016-07-31 Open insert ring to ease level sensor maintenance
    [aquaMonitor.scad, aquaMonitorDemo.stl, insert.stl]
2016-07-31 Thinner insert, sharper pawl teeth
    [aquaMonitor.scad, insert.stl]
2016-08-22 Added main power failure detection on pin A1 Replaced all 'w' in messages with 'W' to workaround issue with GSM module that truncates SMS after any occurrence of 'w'...
    [aquaMonitor.ino]
2016-08-27 Updated schematics with power failure detection Updated list of components
    [aquaMonitor.fzz]
2016-08-28 Now handling a light off schedule Light on and off schedule need min and max light level acceptable values. Status message now includes the topic of an alert, if any. Slightly faster display shifting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
    [aquaMonitor.ino]
2016-08-28 Added pictures of installed device and sensors
2016-08-29 Fixed issue #7: time elapsed since last alert sent It's actually more of a work around, original issue not really explained.
    [aquaMonitor.ino]
2016-08-29 Added 'clear' and 'reset config' commands. 'clear' clears the delay before next alert can be sent 'reset config' cancelled unsaved config modifications
    [aquaMonitor.ino]
2016-09-02 Updated breadboard schema with main power failure detection wiring
2016-09-04 Replaced UNO with Mega in schematics
    [aquaMonitor.fzz]
2016-09-06 Fixing syntax discrepancies with new Arduino SDK release Issue #15
    [aquaMonitor.ino]
2016-09-10 Fixed issue #17: voice call breaking SMS
    [aquaMonitor.ino, aquaNet.ino]
2016-09-10 Fixed issue #17: voice call no longer breaking SMS
    [aquaMonitor.ino]
2016-09-12 Fixed serial comm between ESP and arduino ESM starts AP only if arduino has GSM ESM requests measures and log them periodically (POC)
    [aquaMonitor.ino, aquaNet.ino]
2016-09-14 webPage can send commands to arduino or to ESP
2016-09-24 Fixed serial communication issues between ESP and Arduino
    [aquaMonitor.ino, aquaNet.ino]
2016-09-25 All arduino settings now displayed and editable. Improved UI layout
2016-10-02 Added script to record stats in a mySql database Added script to create tables in the database ESP8266 now periodically posts the stats to the statistics host
    [aquaMonitor.fzz]
2016-10-02 Fixed exchanged alerts/levels for power and water level Removed some debug stuff
    [aquaNet.ino]
2016-10-04 Now displaying chart for temperature and light for the last 24 hours
2016-10-04 Fixed decimal temperature Y axis values now red (temperarure) and blue (light)
2016-10-04 X axis labels now black Fixed merge issue
    [aquaMonitor.ino]
2017-02-25 Adding stl case file to allow preview on github
    [case.stl]
2017-02-25 Added links to case and sensor brackets STL for the "wow" effect.
2017-02-25 A light shield available in the file must be printed separately and glued on top.
    [aquaMonitor.scad, aquaMonitorDemo.stl]
2017-02-26 Rotation of bracket in demo file to show it as when in use.
    [aquaMonitor.scad, aquaMonitorDemo.stl]
2017-07-16 No longer send the unknown message aknowledgement because of dumb spam services
    [aquaMonitor.ino]
2017-10-13 Update LICENSE
    Switched License to Creative Commons Attribution-NonCommercial-ShareAlike 4.0 International Public License
2018-10-28 Light sensor now enclosed in bracket to avoid salt corrosion. Adjusted insert tolerance to Prusa precision
    [aquaMonitor.scad, aquaMonitor10mm.stl, insert.stl]
2022-08-21 Added slt for 6mm glass, updated 'demo' file with new design
    [aquaMonitor.FCStd, aquaMonitor.obj, aquaMonitor.scad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]
2022-08-21 removing old stuff
    [aquaMonitor6mm.stl, aquaMonitorDemo.stl, lightShield-0.stl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]
2023-05-19 New case
    [aquaMonitorCase.FCStd, aquaMonitorCase.obj, aquaMonitorCaseCover.FCStd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]
2026-01-11 Revise README to reflect project status and future plans
    Updated README to indicate project discontinuation and future plans for a new ESP32-based project.
